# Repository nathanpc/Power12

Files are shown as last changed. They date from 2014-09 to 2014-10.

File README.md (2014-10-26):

# Power12

A compact 6 watts per channel amplifier.

Completed

## Schematic

It's a very simple discrete power amplifier with a [CFP output stage](http://en.wikipedia.org/wiki/Sziklai_pair).

Schematic

PCB Layout

## Distortion

*Rev A*

Here's the THD x Frequency plot created using [plot_thd.py](https://gist.github.com/nathanpc/464b65f48d494179be13):

THD Plot

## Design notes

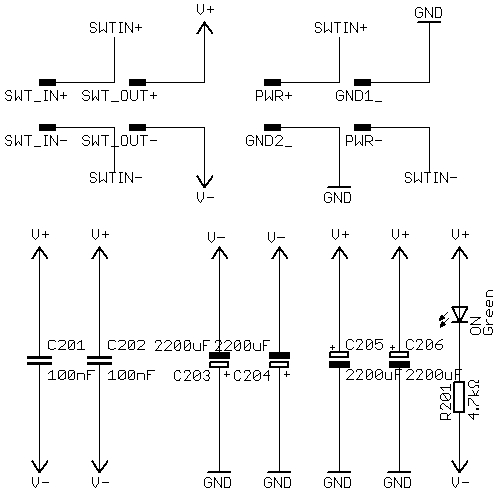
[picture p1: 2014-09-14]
images/Power Supply.png

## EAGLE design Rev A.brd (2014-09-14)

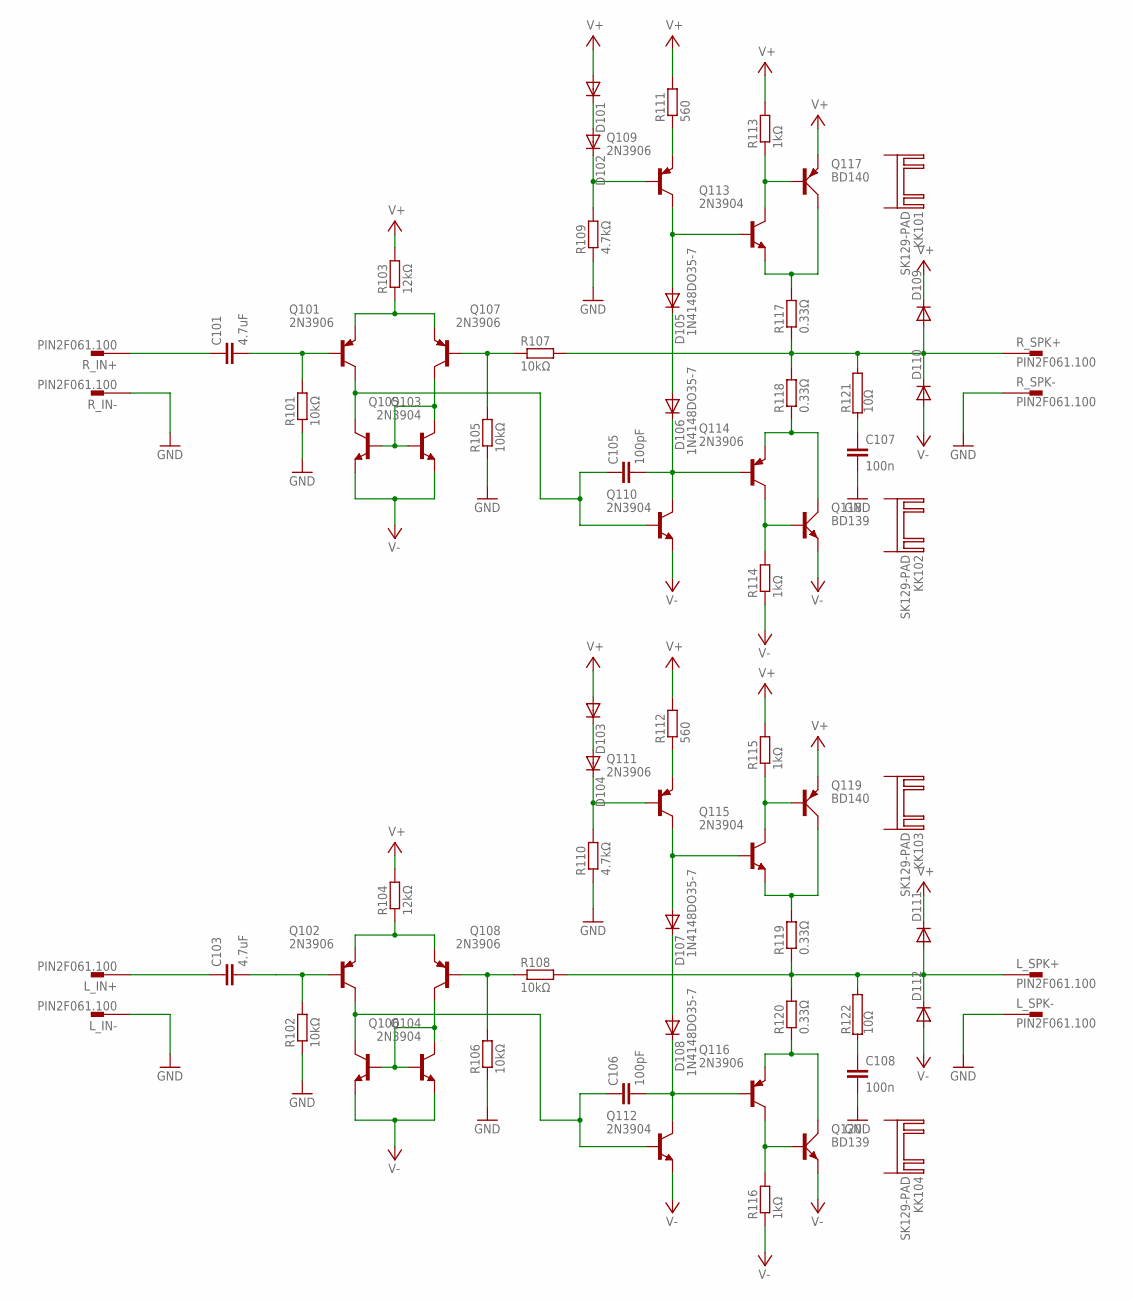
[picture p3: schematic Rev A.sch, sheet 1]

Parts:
C101, C103: 4.7uF; C225-113X268
C105, C106: 100pF; C050-050X075
C107, C108: 100n; C075-042X103
D101, D102, D103, D104, D105, D106, D107, D108, D109, D110, D111, D112: 1N4148DO35-7; DO35-7
KK101, KK102, KK103, KK104: SK129-PAD; SK129
L_IN+: PIN2F061.100; F061.100
L_IN-: PIN2F061.100; F061.100
L_SPK+: PIN2F061.100; F061.100
L_SPK-: PIN2F061.100; F061.100
Q101, Q102, Q107, Q108, Q109, Q111, Q114, Q116: 2N3906; TO92
Q103, Q104, Q105, Q106, Q110, Q112, Q113, Q115: 2N3904; TO92
Q117, Q119: BD140; TO126AV
Q118, Q120: BD139; TO126AV
R101, R102, R105, R106, R107, R108: 10kΩ; 0207/10
R103, R104: 12kΩ; 0207/10
R109, R110: 4.7kΩ; 0207/10
R111, R112: 560; 0207/10
R113, R114, R115, R116: 1kΩ; 0207/10
R117, R118, R119, R120: 0.33Ω; 0309/12
R121, R122: 10Ω; MNS-5
R_IN+: PIN2F061.100; F061.100
R_IN-: PIN2F061.100; F061.100
R_SPK+: PIN2F061.100; F061.100
R_SPK-: PIN2F061.100; F061.100

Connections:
GND: C107.2, C108.2, L_IN-.A1, L_IN-.A2, L_SPK-.A1, L_SPK-.A2, R101.1, R102.1, R105.1, R106.1, R109.1, R110.1, R_IN-.A1, R_IN-.A2, R_SPK-.A1, R_SPK-.A2; also elsewhere on the board
L_OUT: D111.A, D112.C, L_SPK+.A1, L_SPK+.A2, R108.2, R119.1, R120.2, R122.2
unnamed: D105.A, Q109.1 (C), Q113.2 (B)
unnamed: Q101.3 (E), Q107.3 (E), R103.1
unnamed: Q103.2 (B), Q105.1 (C), Q105.2 (B), Q107.1 (C)
unnamed: Q104.2 (B), Q106.1 (C), Q106.2 (B), Q108.1 (C)
unnamed: C101.2, Q101.2 (B), R101.2
unnamed: D102.C, Q109.2 (B), R109.2
unnamed: C101.1, R_IN+.A1, R_IN+.A2
unnamed: C105.1, Q101.1 (C), Q103.1 (C), Q110.2 (B)
unnamed: D101.C, D102.A
unnamed: Q109.3 (E), R111.1
unnamed: D104.C, Q111.2 (B), R110.2
unnamed: D103.C, D104.A
unnamed: Q111.3 (E), R112.1
unnamed: C103.1, L_IN+.A1, L_IN+.A2
unnamed: C107.1, R121.1
unnamed: C108.1, R122.1
unnamed: D105.C, D106.A
unnamed: C103.2, Q102.2 (B), R102.2
unnamed: Q113.1 (C), Q117.B, R113.1
unnamed: Q114.1 (C), Q118.B, R114.2
unnamed: Q114.3 (E), Q118.C, R118.1
unnamed: Q113.3 (E), Q117.C, R117.2
unnamed: C105.2, D106.C, Q110.1 (C), Q114.2 (B)
unnamed: Q107.2 (B), R105.2, R107.1
unnamed: Q102.3 (E), Q108.3 (E), R104.1
unnamed: C106.1, Q102.1 (C), Q104.1 (C), Q112.2 (B)
unnamed: D107.C, D108.A
unnamed: D107.A, Q111.1 (C), Q115.2 (B)
unnamed: Q115.1 (C), Q119.B, R115.1
unnamed: Q115.3 (E), Q119.C, R119.2
unnamed: Q116.1 (C), Q120.B, R116.2
unnamed: Q116.3 (E), Q120.C, R120.1
unnamed: C106.2, D108.C, Q112.1 (C), Q116.2 (B)
unnamed: Q108.2 (B), R106.2, R108.1
R_OUT: D109.A, D110.C, R107.2, R117.1, R118.2, R121.2, R_SPK+.A1, R_SPK+.A2
V+: D101.A, D103.A, D109.C, D111.C, Q117.E, Q119.E, R103.2, R104.2, R111.2, R112.2, R113.2, R115.2; also elsewhere on the board
V-: D110.A, D112.A, Q103.3 (E), Q104.3 (E), Q105.3 (E), Q106.3 (E), Q110.3 (E), Q112.3 (E), Q118.E, Q120.E, R114.1, R116.1; also elsewhere on the board

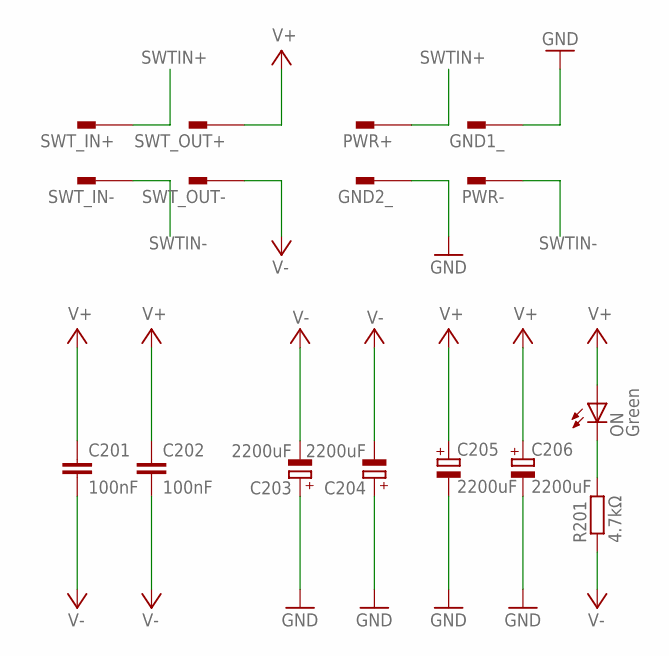
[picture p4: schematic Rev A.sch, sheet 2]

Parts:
C201, C202: 100nF; C025-025X050
C203, C204, C205, C206: 2200uF; E5-10,5
GND1_, GND2_: PIN2F061.100; F061.100
ON: Green; LED5MM
PWR+: PIN2F061.100; F061.100
PWR-: PIN2F061.100; F061.100
R201: 4.7kΩ; 0207/10
SWT_IN+: PIN2F061.100; F061.100
SWT_IN-: PIN2F061.100; F061.100
SWT_OUT+: PIN2F061.100; F061.100
SWT_OUT-: PIN2F061.100; F061.100

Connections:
GND: C203.+, C204.+, C205.-, C206.-, GND1_.A1, GND1_.A2, GND2_.A1, GND2_.A2; also elsewhere on the board
unnamed: ON.K (C), R201.2
SWTIN+: PWR+.A1, PWR+.A2, SWT_IN+.A1, SWT_IN+.A2
SWTIN-: PWR-.A1, PWR-.A2, SWT_IN-.A1, SWT_IN-.A2
V+: C201.1, C202.1, C205.+, C206.+, ON.A, SWT_OUT+.A1, SWT_OUT+.A2; also elsewhere on the board
V-: C201.2, C202.2, C203.-, C204.-, R201.1, SWT_OUT-.A1, SWT_OUT-.A2; also elsewhere on the board

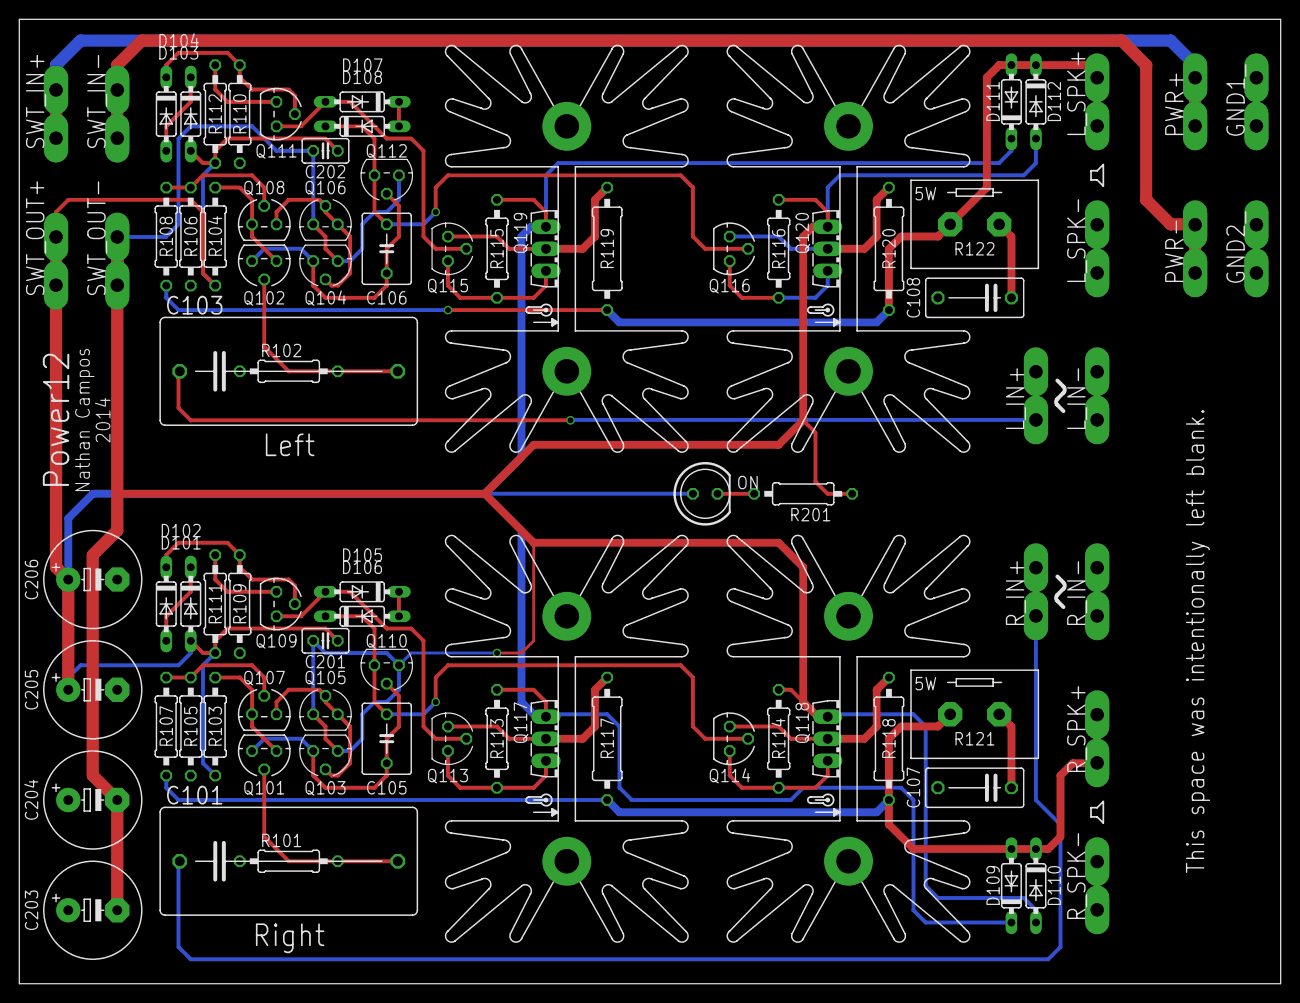
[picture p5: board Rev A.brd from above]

Board: 4 copper layers, 130.8 x 100.0 mm, 96 parts (0 on the bottom side), 42 nets.

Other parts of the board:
U$1, U$2: ICON_SPEAKER
U$3, U$4, U$5, U$6: ICON_TEMP
U$7, U$8: ICON_AC

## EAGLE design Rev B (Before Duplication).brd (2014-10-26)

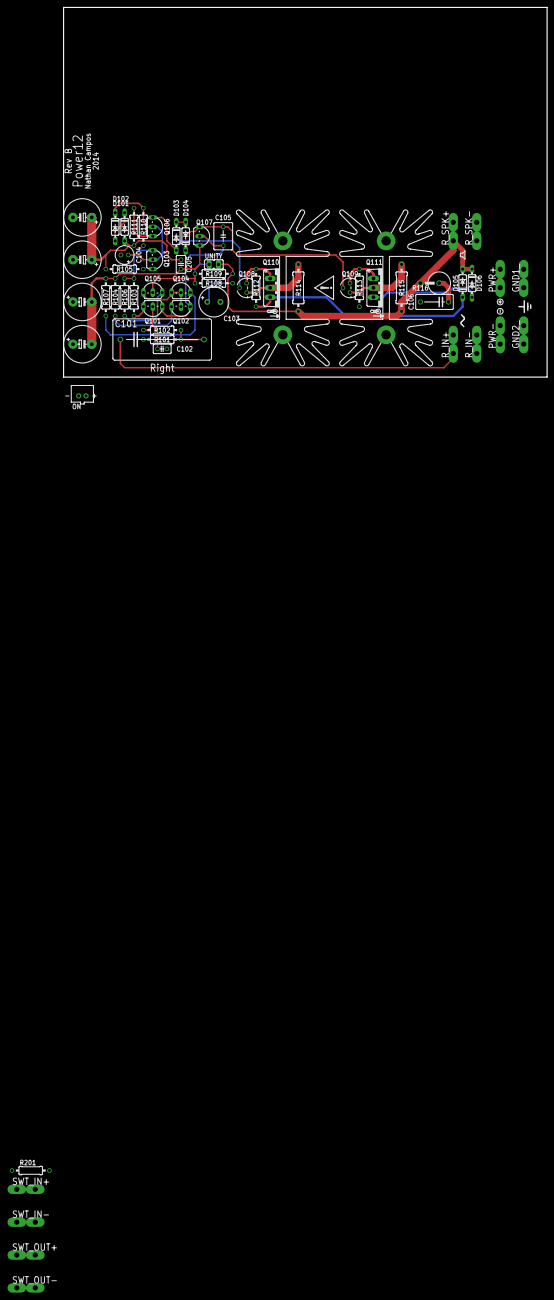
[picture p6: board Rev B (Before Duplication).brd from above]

Board: 4 copper layers, 130.8 x 100.0 mm, 69 parts (0 on the bottom side), 31 nets.

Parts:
C101: 4.7uF; C225-113X268
C102: 10nF; C025-025X050
C103: 220uF; E3,5-8
C104: 2.2uF; E2-5
C105: 100pF; C050-050X075
C106: 100n; C075-042X103
C201, C202, C203, C204: 2200uF; E5-10,5
C205: 100nF; C025-025X050
D101, D102, D103, D104, D105, D106: 1N4148DO35-7; DO35-7
GND1_, GND2_: PIN2F061.100; F061.100
KK101, KK102: SK129-PAD; SK129
ON: JST-PH-2-THM
PWR+: PIN2F061.100; F061.100
PWR-: PIN2F061.100; F061.100
Q101, Q103, Q105, Q106: BC560C; TO92-EBC
Q102, Q104, Q107: BC550B; TO92-EBC
Q108: 2N3904; TO92
Q109: 2N3906; TO92
Q110: TIP42C; TO220AV
Q111: TIP41C; TO220AV
R101, R109: 10kΩ; 0207/10
R102, R105: 100Ω; 0207/10
R103, R106: 22Ω; 0207/10
R104, R107: 56Ω; 0207/10
R108: 560Ω; 0207/10
R110, R201: 4.7kΩ; 0207/10
R111: 560; 0207/10
R112, R113: 1kΩ; 0207/10
R114, R115: 0.33Ω; 0309/12
R116: 10Ω; 0617V
R_IN+: PIN2F061.100; F061.100
R_IN-: PIN2F061.100; F061.100
R_SPK+: PIN2F061.100; F061.100
R_SPK-: PIN2F061.100; F061.100
SWT_IN+: PIN2F061.100; F061.100
SWT_IN-: PIN2F061.100; F061.100
SWT_OUT+: PIN2F061.100; F061.100
SWT_OUT-: PIN2F061.100; F061.100
U$1: ICON_SPEAKER
U$2: ICON_GND2
U$3: ICON_PLUS
U$4: ICON_MINUS
U$5, U$6: ICON_TEMP
U$7: ICON_AC
U$9: ICON_EXL-S
UNITY: JP1

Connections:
GND: C102.2, C103.-, C104.-, C106.2, C201.+, C202.+, C203.-, C204.-, GND1_.A1, GND1_.A2, GND2_.A1, GND2_.A2, R101.1, R110.1, R_IN-.A1, R_IN-.A2, R_SPK-.A1, R_SPK-.A2
unnamed: D103.A, Q106.C, Q108.2
unnamed: Q105.E, R106.1
unnamed: Q102.B, Q104.B, Q104.C, Q105.C
unnamed: C102.1, Q101.B, R102.2
unnamed: C101.2, R101.2, R102.1
unnamed: C104.+, D102.C, Q103.B, Q106.B, R110.2
unnamed: C101.1, R_IN+.A1, R_IN+.A2
unnamed: C105.1, Q101.C, Q102.C, Q107.B
unnamed: D101.C, D102.A
unnamed: ON.2, R201.2
unnamed: Q106.E, R111.1
unnamed: C103.+, R108.1
unnamed: Q102.E, R104.2
unnamed: Q104.E, R107.2
unnamed: C106.1, R116.1
unnamed: Q101.E, R103.1
unnamed: Q103.C, R103.2, R106.2
unnamed: Q103.E, R105.1
unnamed: D103.C, D104.A
unnamed: Q108.1, Q110.B, R112.1
unnamed: Q109.1, Q111.B, R113.2
unnamed: Q109.3, Q111.C, R115.1
unnamed: Q108.3, Q110.C, R114.2
unnamed: C105.2, D104.C, Q107.C, Q109.2
unnamed: Q105.B, R108.2, R109.1, UNITY.1
R_OUT: D105.A, D106.C, R109.2, R114.1, R115.2, R116.2, R_SPK+.A1, R_SPK+.A2, UNITY.2
SWTIN+: PWR+.A1, PWR+.A2, SWT_IN+.A1, SWT_IN+.A2
SWTIN-: PWR-.A1, PWR-.A2, SWT_IN-.A1, SWT_IN-.A2
V+: C203.+, C204.+, C205.1, D101.A, D105.C, ON.1, Q110.E, R105.2, R111.2, R112.2, SWT_OUT+.A1, SWT_OUT+.A2
V-: C201.-, C202.-, C205.2, D106.A, Q107.E, Q111.E, R104.1, R107.1, R113.1, R201.1, SWT_OUT-.A1, SWT_OUT-.A2

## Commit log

2014-09-13 Final schematic?
    [Rev A.sch]
2014-09-13 Switched every JST connector to a Faston tab
    [Rev A.sch]
2014-09-13 Components placed
    [Rev A.brd]
2014-09-14 Finished the board layout
    [Rev A.brd]
2014-09-14 Exported the schematic
2014-10-12 Temperature profile
    [Power12-Oct6.csv]
2014-10-12 Added the SPICE circuit and the THD plot
2014-10-12 Added the temperature profile plot
2014-10-25 Started working on Rev B
    [Rev B.brd, Rev B.sch]
2014-10-26 Finished routing one side
    [Rev B.brd, Rev B.sch]
2014-10-26 Rev B
    [Rev B (Before Duplication).brd, Rev B.sch]

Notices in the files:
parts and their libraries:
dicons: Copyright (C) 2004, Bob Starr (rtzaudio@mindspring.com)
